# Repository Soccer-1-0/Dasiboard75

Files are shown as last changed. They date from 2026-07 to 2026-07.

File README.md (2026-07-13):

# Dasiboard75

This is my attempt at creating a keyboard with 84 keys, with backlights, a rotary encoder, a slide potentiometer, a OLED screen, and a power switch, using just the 19 usable pins of a XIAO NRF52840 Plus. I named it dasiboard75 because I liked the unique way to spell it and it just sounds like a cool keyboard.
Render

## CAD
Cadding everything together was the best part, since I could easily see the results fast and I didn't have to worry about any problems later in firmware. The keys will also be colored, since there is a keyset that I sourced that provides variations of light green keys, I just didn't want to add color to every individual key. I also made custom knobs for both the slide potentiometer and the rotary encoder! Dasiy flower for the encoder! Also, since I couldn't fit the file size in github for the assembly, view and download the complete assembly here: https://a360.co/4feVppu

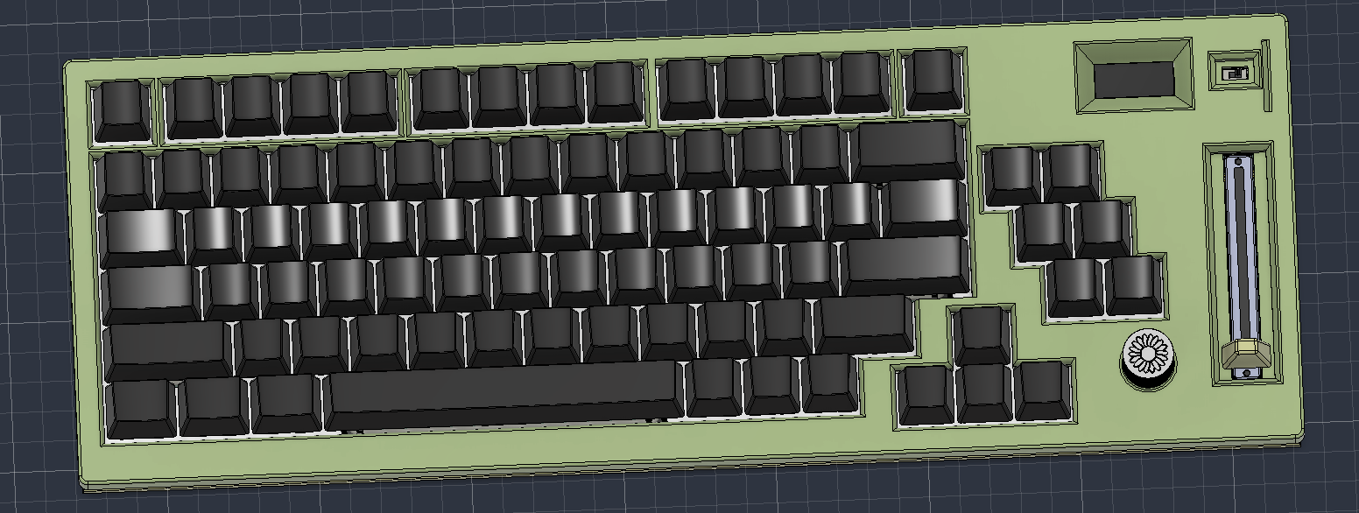
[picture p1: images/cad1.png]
cad1

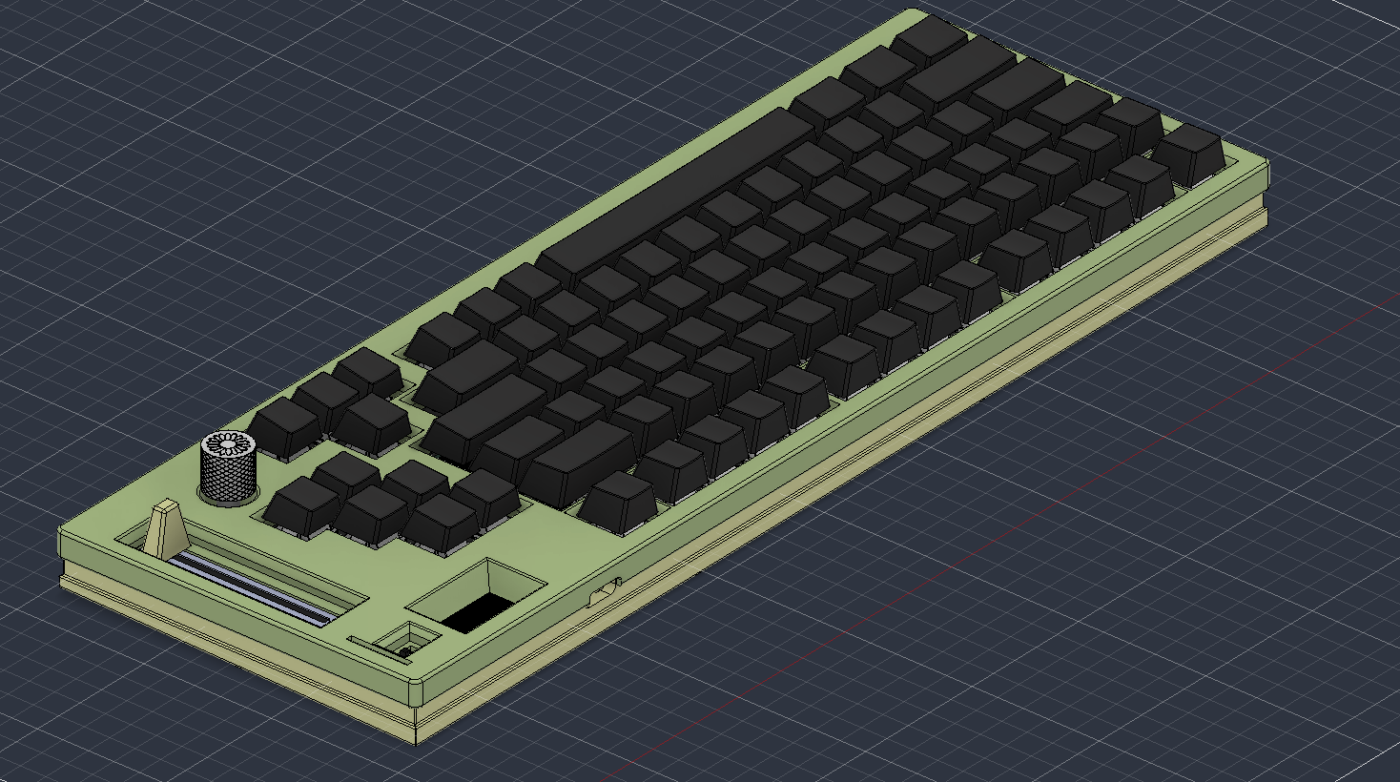
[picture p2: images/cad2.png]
cad2


## Schematic
My schematics are so cooked that I need three images for this. The leds took so much space, but it only takes on gpio pin. I used the japanese duplex matrix, which is why there are two keys for each column in the schematic drawing for the switiches. The duplex matrix works with scanning with the different directions of diodes to be able to double the amount of keys on a keyboard, which is the main reason I was able to make a full keyboard with less pins.
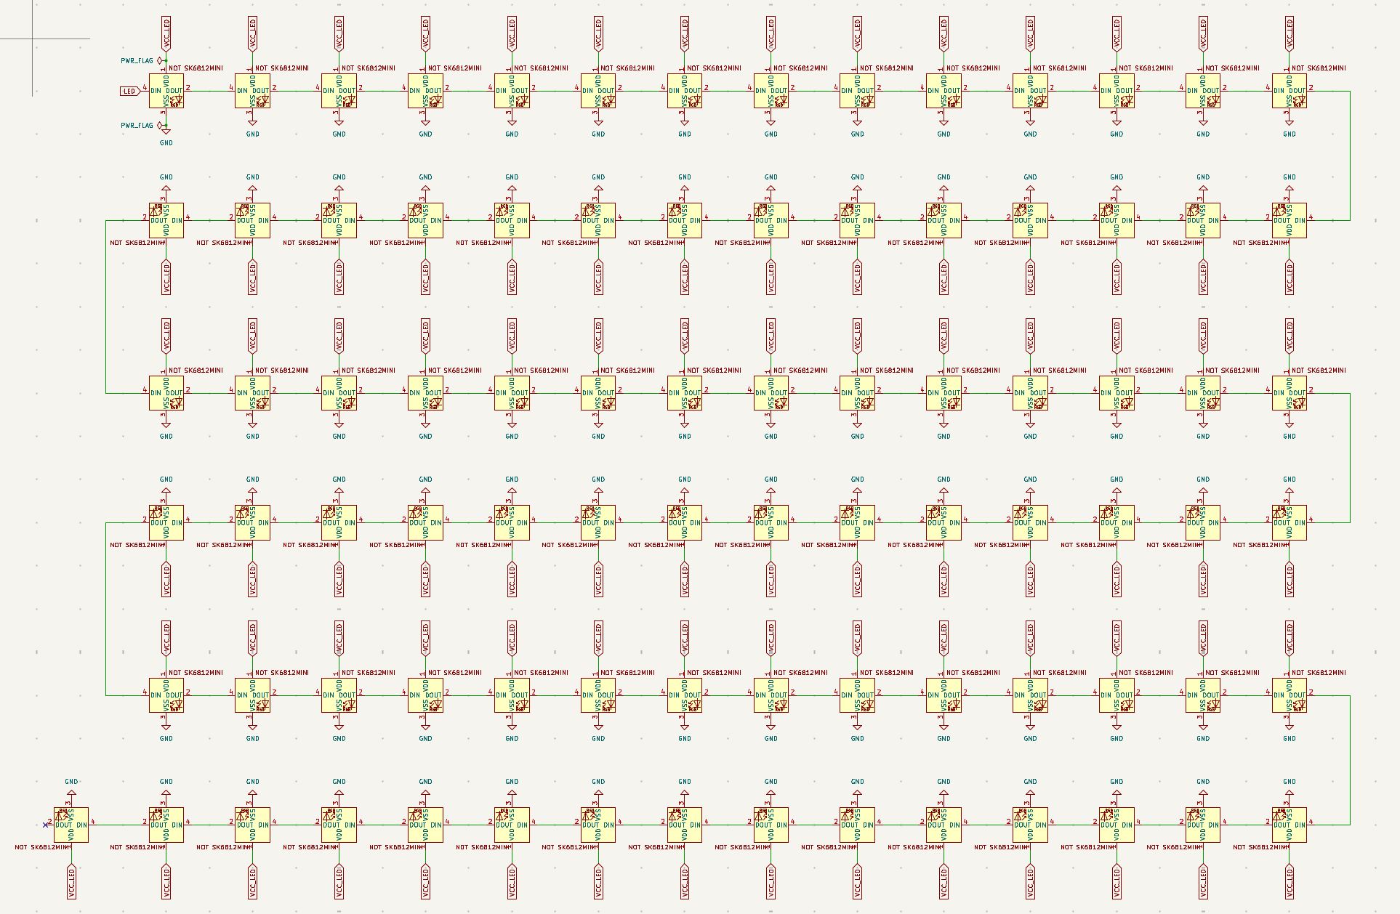
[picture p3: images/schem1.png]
schem1

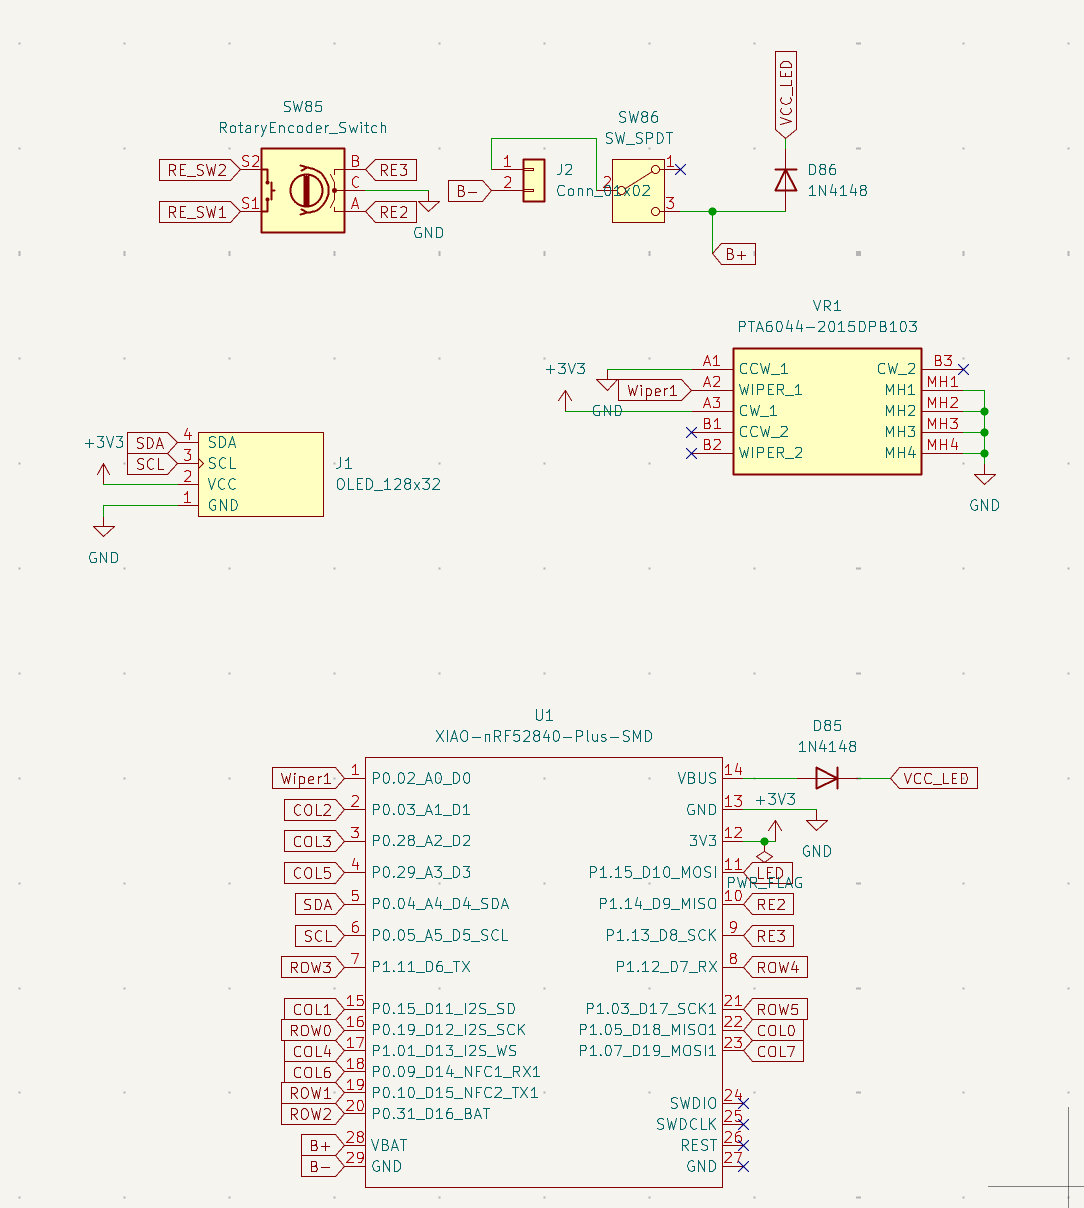
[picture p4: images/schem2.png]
schem2

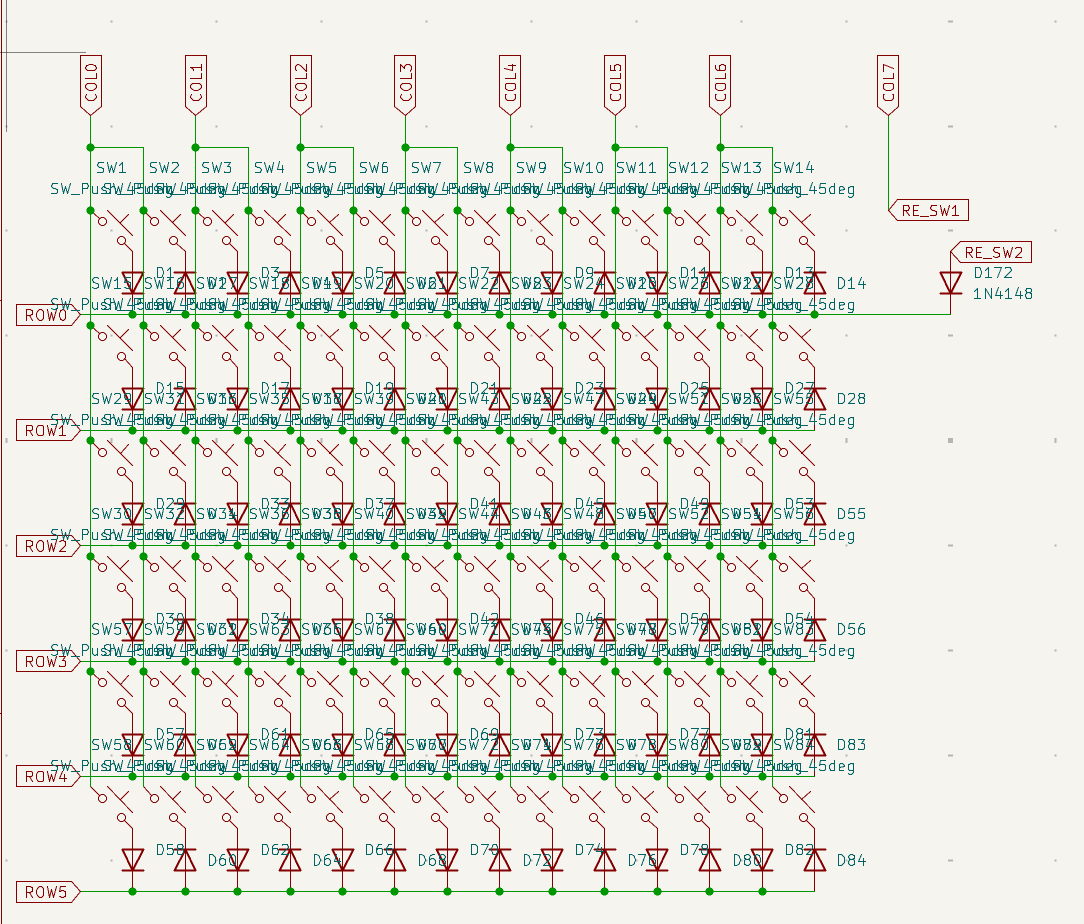
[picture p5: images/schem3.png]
schem3


## PCB
The routing of this took so long, since I used a 7x7(2) matrix for it, I had to move all the switiches to make sure they all connected the same way. The routing of the leds were even worse.
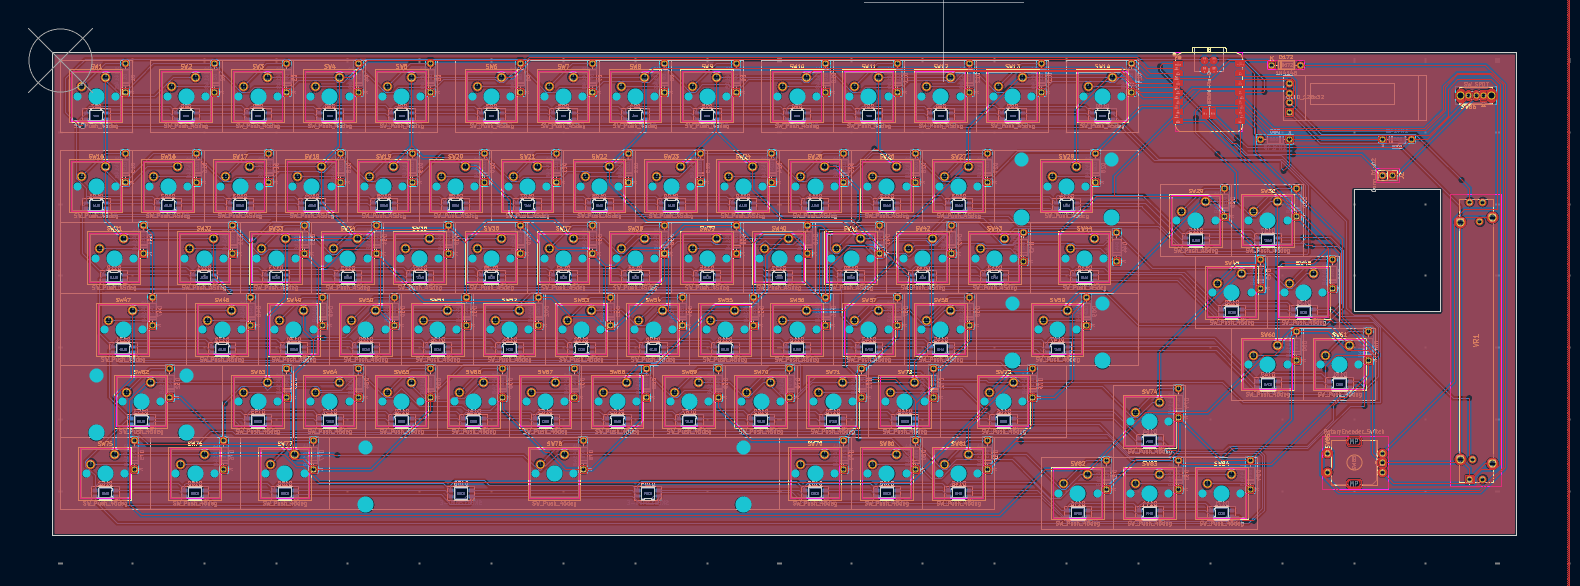
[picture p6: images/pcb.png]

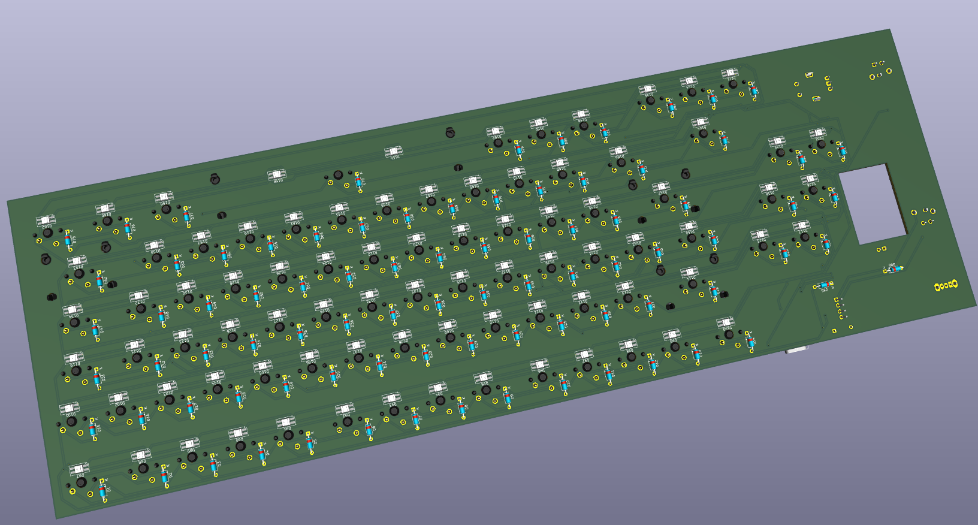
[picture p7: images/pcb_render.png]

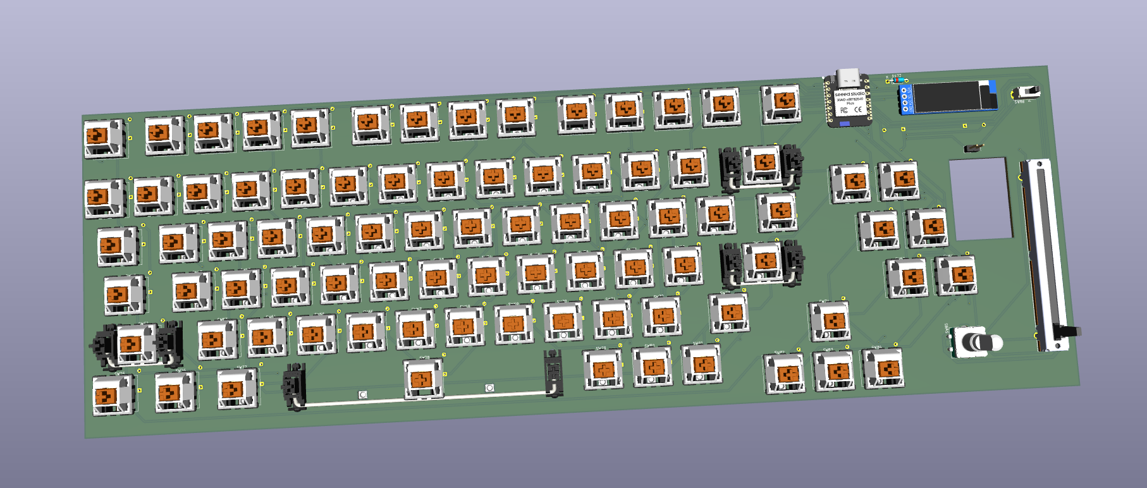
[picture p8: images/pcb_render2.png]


## Firmware
Still in progress, am trying to find a way for it to work with ZMK firmware, since some of my features are not supported with ZMK, but I really want to use the energy saving ways of bluetooth of ZMK. UPDATE: firmware: https://github.com/Soccer-1-0/zmk-config

## Casing
The casing took a very annoying long time. The plate itself took a long time since I used a keyboard layout generator, but then moved the keys during the routing process for a smaller pcb. I also had to add a bunch of holes for heat inserts, and screws, and the heads of the screws since I used a bottom mount for my keyboard (search it up, its a keyboard type of conencting between the plates and casing). But overall, I like how the casing ended up, I kinda wanted to add another part of casing to protect the keys and knobs, but we'll see if I actuall add it later.
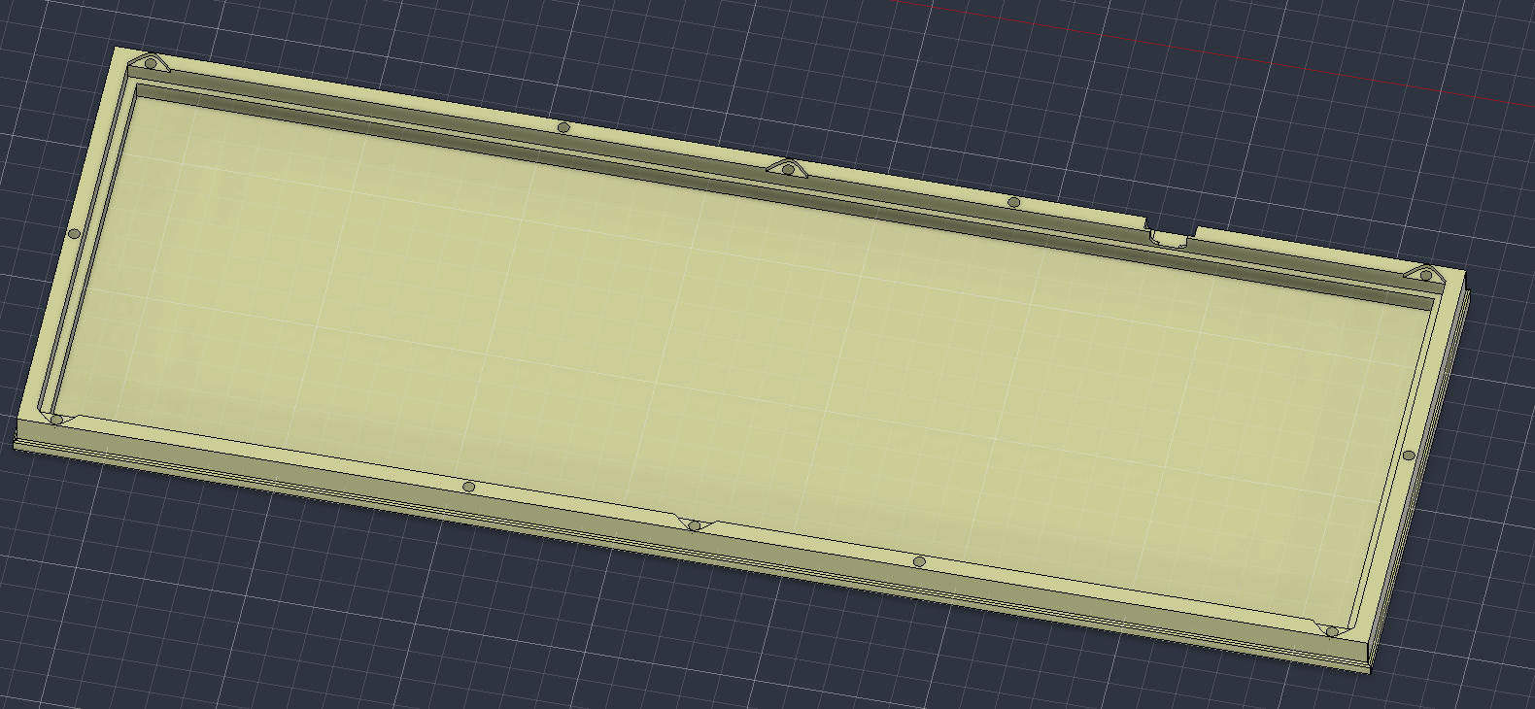
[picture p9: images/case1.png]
case1

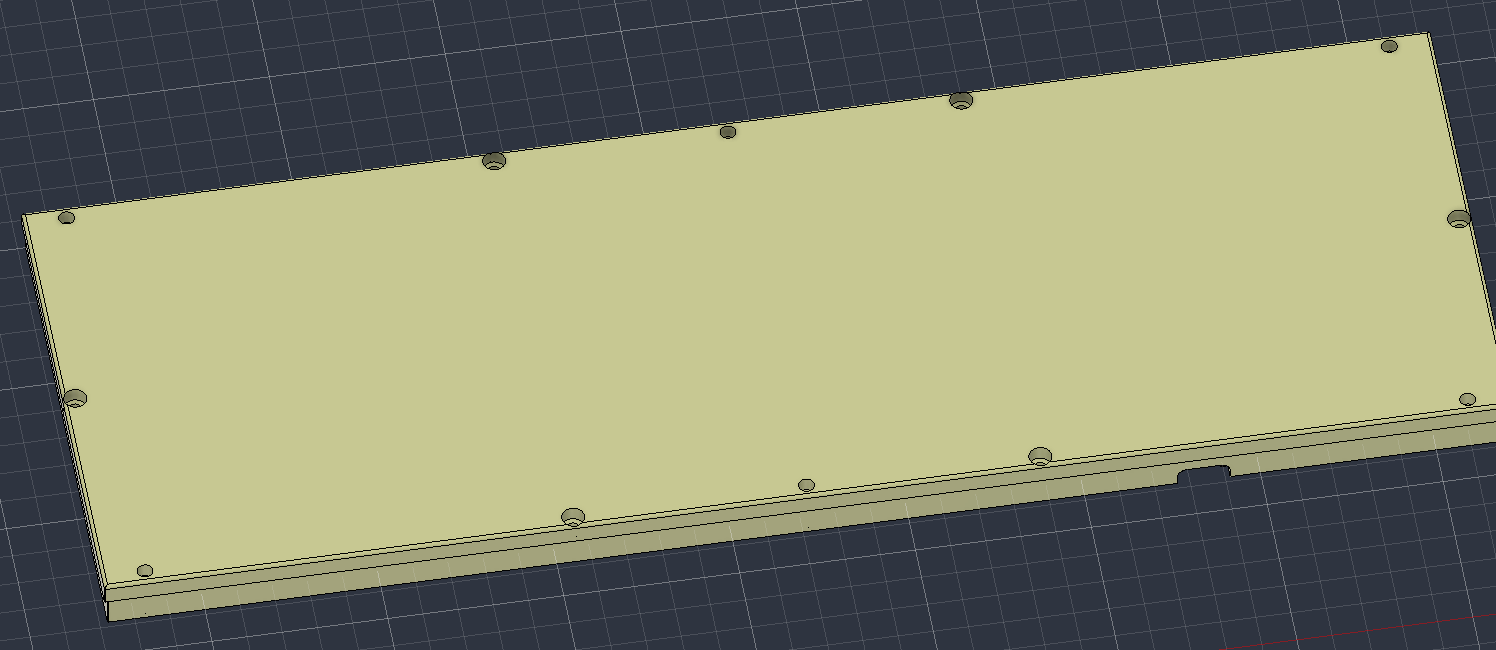
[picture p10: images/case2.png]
case2

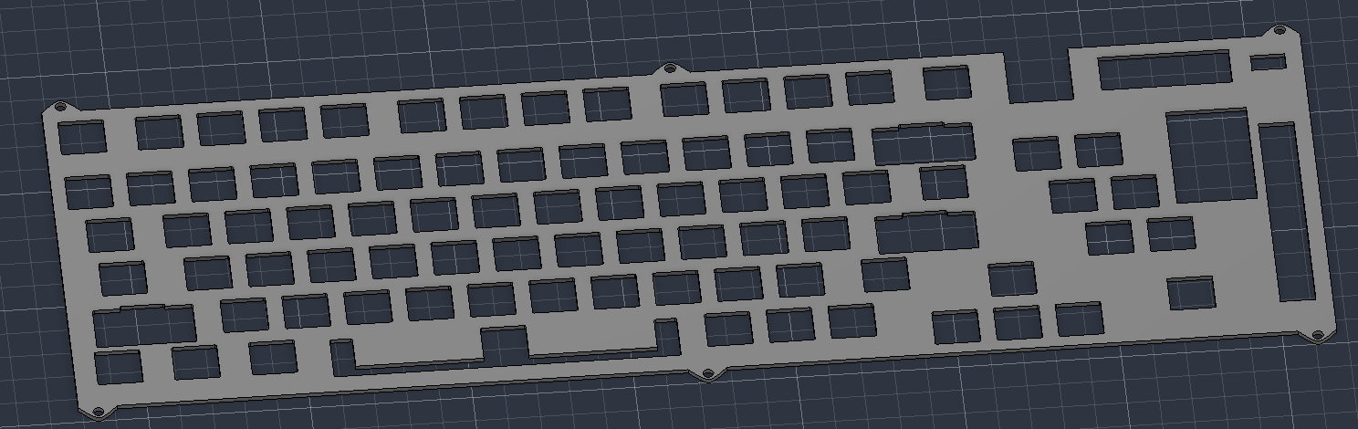
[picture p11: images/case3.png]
case3

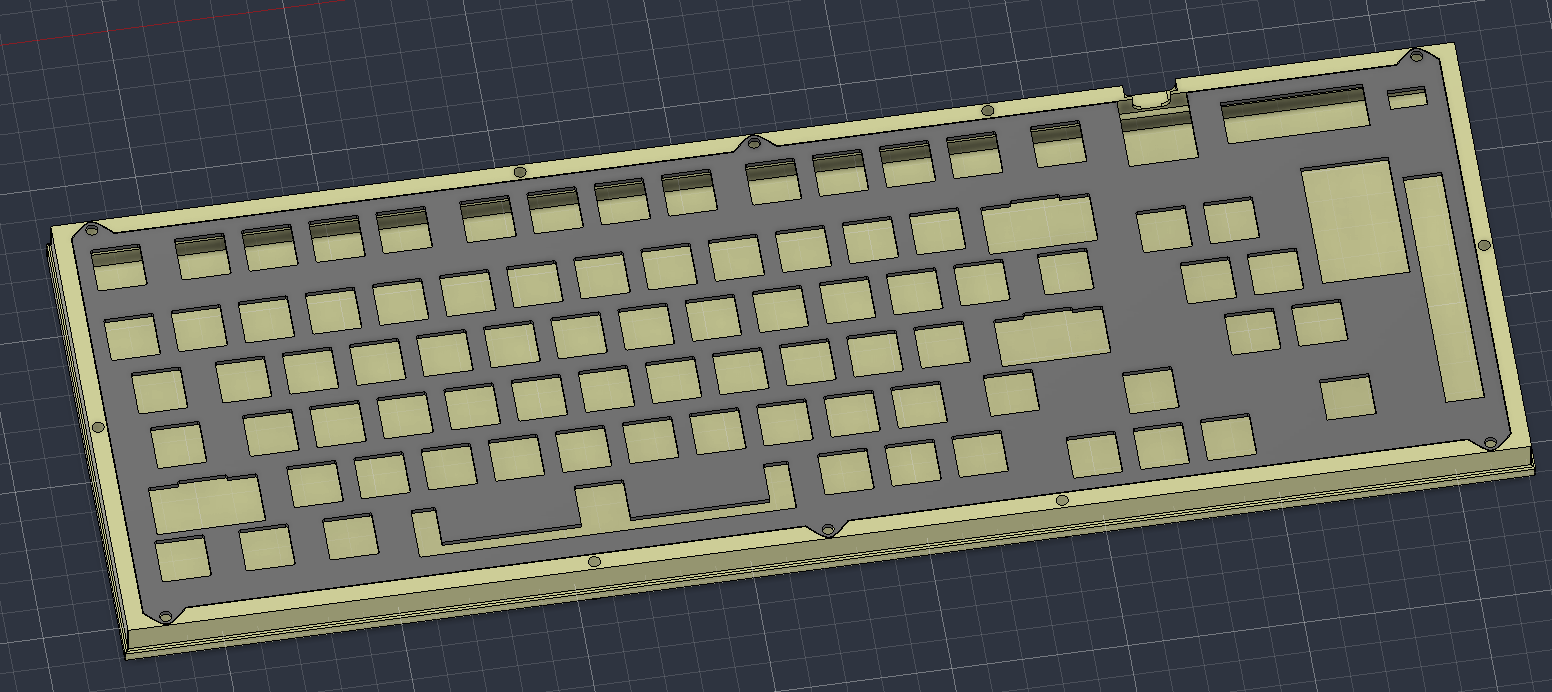
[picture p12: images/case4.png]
case4

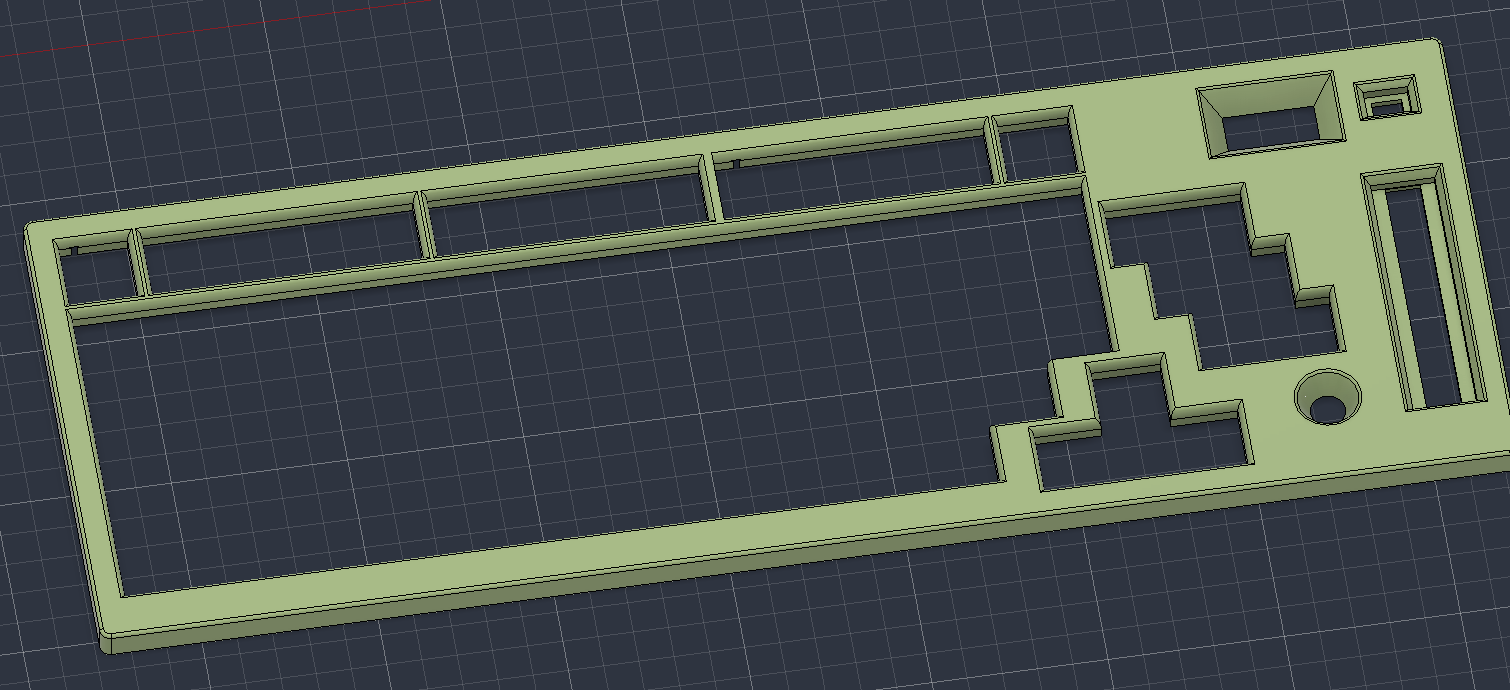
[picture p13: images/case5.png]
case5

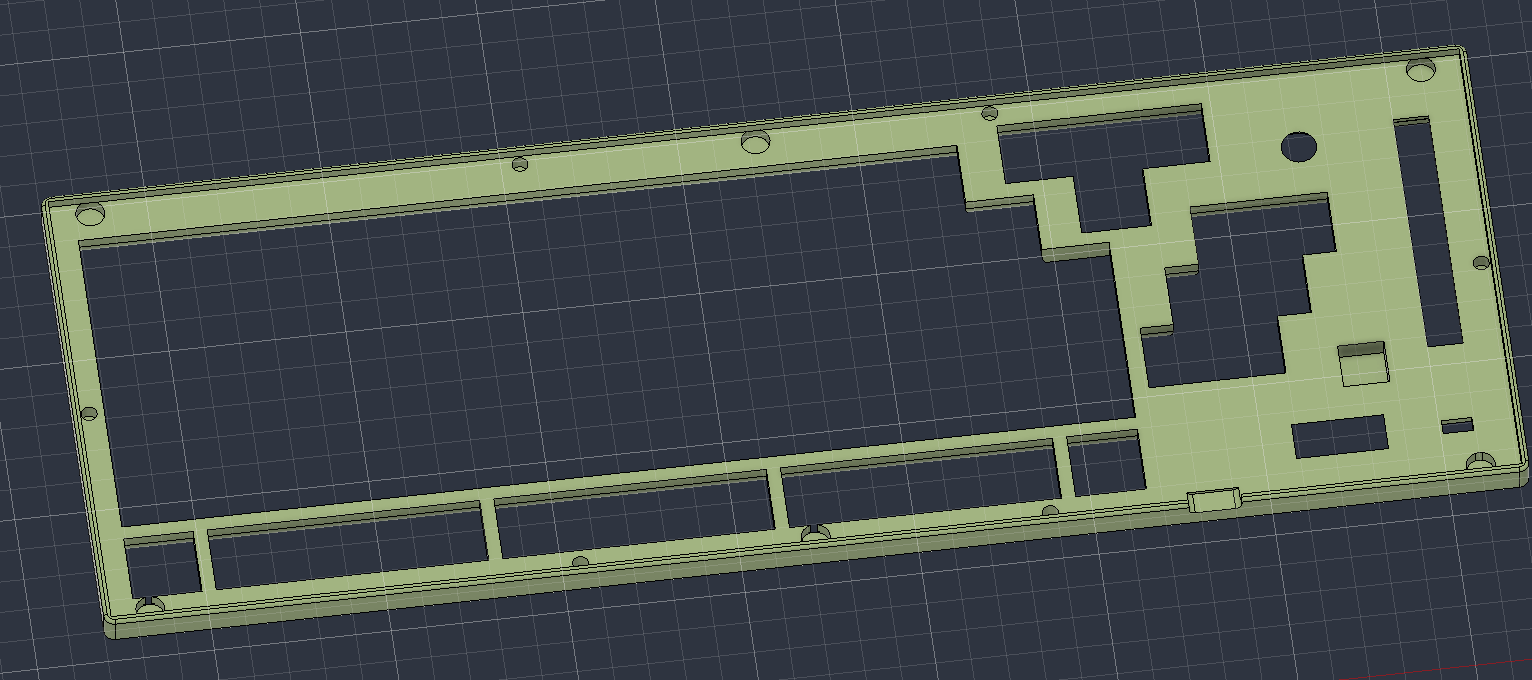
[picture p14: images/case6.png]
case6

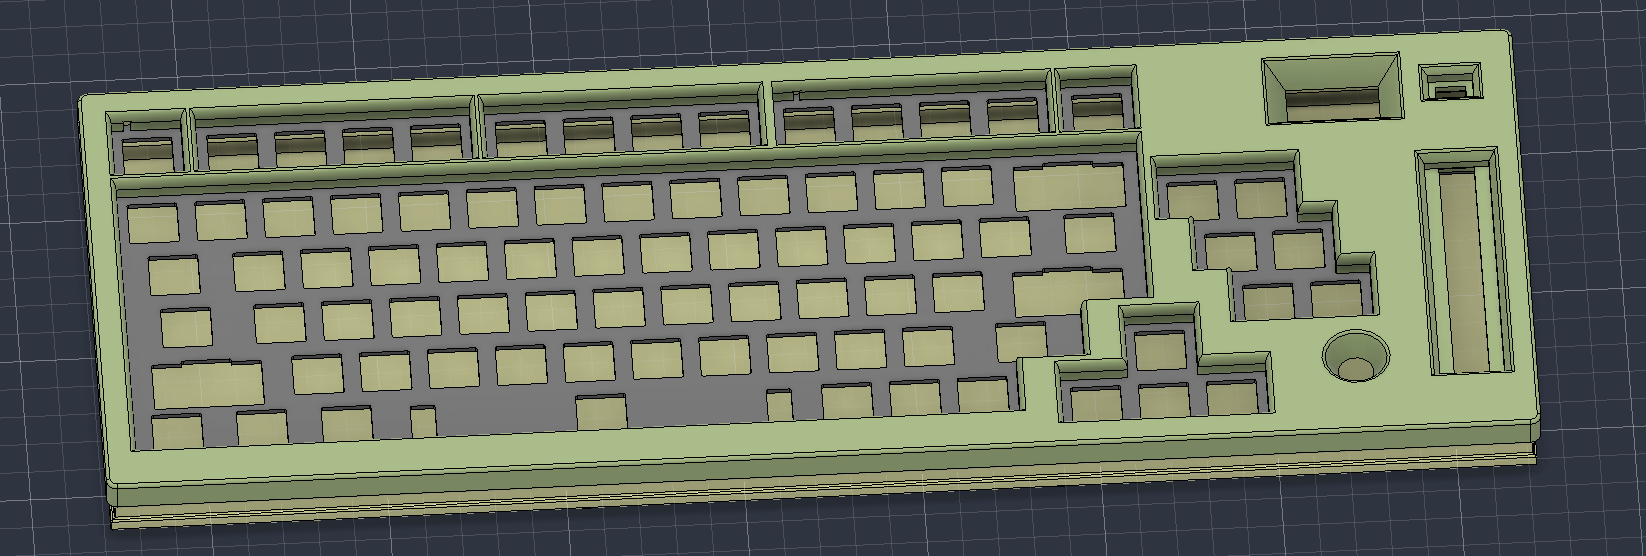
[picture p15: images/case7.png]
case7


## BOM
- PCB
- Casing
- Keycaps
- 1N4148 Diodes
- 0.91 OLED Display
- 6.0U and 2.0 stabilizers
- Key Switches
- Rotary Encoder
- Slide Potentiometer
- Xiao NRF52840
- SK6812 Mini E LEDs
- SPDT Switch
- Rotary and Slider Knobs
- Litho Battery
- M3x18 Screws
View more indepth in the BOM file

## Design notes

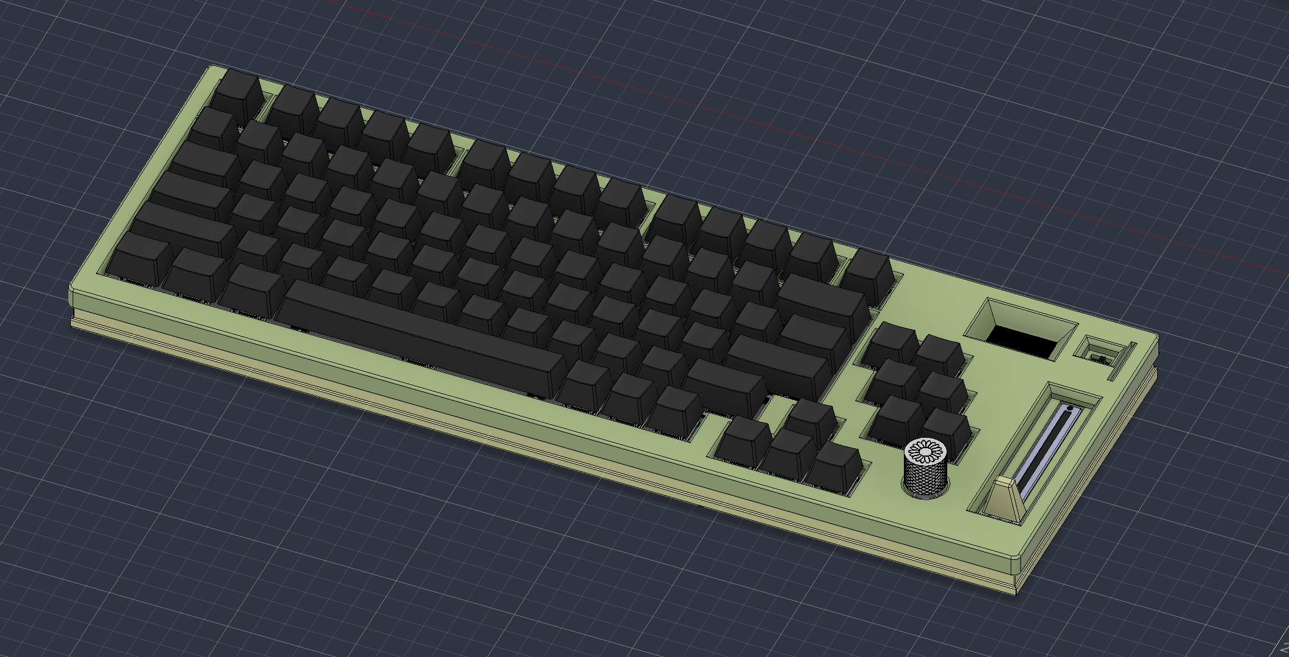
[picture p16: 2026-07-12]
images/Render.png

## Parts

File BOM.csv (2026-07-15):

Part | Quantity | Purpose | Shown Price | Link
PCB | 1 | Main body for components and wiring |  | JLCPCB
Casing | 1 | Holds the pcba and other parts |  | 3d printed (Printing Legion I think)
Keycaps | 84 | For the keyswitches, and found a good set | $18.01 | https://www.aliexpress.us/item/3256807174517233.html?mp=1&_randl_shipto=US
1N4148 Diodes | 86 | For the keyswitches to be able to work | $2.51 | aliexpress.us/item/3256811580628264.html?spm=a2g0o.detail.0.0.1678d7Qxd7QxvC&mp=1&pdp_npi=6%40dis%21USD%21USD%202.63%21USD%202.51%21%21USD%202.51%21%21%21%402103138417839779934458576e1043%2112000056498191665%21ct%21US%217763341167%21%211%210%21&gatewayAdapt=glo2usa&_randl_shipto=US
0.91 OLED Display | 1 | The display, for battery power and others | $2.48 | aliexpress.us/item/3256809902820804.html?spm=a2g0o.detail.0.0.28ebT1mST1mSgm&mp=1&pdp_npi=6%40dis%21USD%21USD%204.96%21USD%202.48%21%21USD%202.48%21%21%21%402103138417839779125795057e1043%2112000051099314066%21ct%21US%217763341167%21%211%210%21&gatewayAdapt=glo2usa&_randl_shipto=US
6.0U and 2.0 stabilizers | 1 | To stabilize the bigger keys | $5.78 | https://www.aliexpress.us/item/3256807050530252.html?curPageLogUid=pjmGXizb0fzy
Key Switches | 84 | For input so the keys actually work | $8.83 | https://www.aliexpress.us/item/3256804099108371.html?curPageLogUid=7E7eGrCkenkF
Rotary Encoder | 1 | The rotary knob for twist, turns, and push and pulls | $1.99 | https://www.aliexpress.us/item/3256805796819763.html?mp=1
Slide Potentiometer | 1 | The part for the sliding knob, for audio or brightness. | $2.78 | https://www.mouser.com/en/ProductDetail/Bourns/PTA6044-2015DPB103?qs=QARuOjD9jaFuTF8TgGb%252B8w%3D%3D
Xiao NRF52840 Plus | 1 | The microcontroller for everything | $10.40 | https://www.seeedstudio.com/Seeed-Studio-XIAO-nRF52840-Plus-p-6359.html
SK6812 Mini E LEDs | 84 | For backlighting behind every key | $3.64 | https://www.aliexpress.us/item/3256807677321116.html?mp=1
SPDT Switch | 1 | The on and off switch for the keyboard | $0.94 | https://www.aliexpress.us/item/3256806935214912.html?mp=1
Rotary and Slider Knobs | 1 | To have a smoother twist and pulls |  | 3d printed (Printing Legion I think)
Litho Battery | 1 | Battery for the bluetooth keyboard | $8.72 | aliexpress.us/item/3256806397828855.html?spm=a2g0o.detail.0.0.70d5xdl5xdl5jD&mp=1&pdp_npi=6%40dis%21USD%21USD%208.46%21USD%205.16%21%21USD%205.16%21%21%21%402103138417839775579492725e1043%2112000037729349745%21ct%21US%217763341167%21%211%210%21&pdp_ext_f=%7B"cart2PdpParams"%3A%7B"pdpBusinessMode"%3A"retail"%7D%7D&gatewayAdapt=glo2usa&_randl_shipto=US
M3x20 Screws | 1 | Holds and keeps the casing together | $6.89 | aliexpress.us/item/3256801577740069.html?spm=a2g0o.cart.0.0.65ad38daEhH0D6&mp=1&pdp_npi=6%40dis%21USD%21USD%207.33%21USD%206.89%21%21USD%206.89%21%21%21%402101c4ea17840741258056476e0ee8%2112000017472790054%21ct%21US%217763341167%21%211%210%21&gatewayAdapt=glo2usa&_randl_shipto=US
M3x22 Screws | 1 | Holds and keeps the casing together | $3.68 | https://www.aliexpress.us/item/3256808936789372.html?mp=1
Total Prices (Plus Shipping)
JLCPCB | $42.16
Aliexpress | $85.78
SeeedStudio | $17.81
Mouser | $12.74
Total | $160

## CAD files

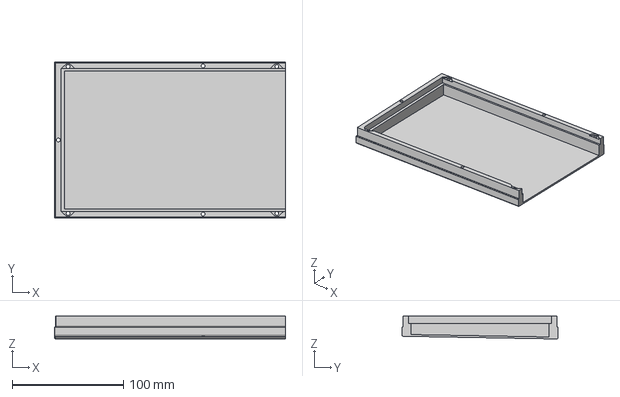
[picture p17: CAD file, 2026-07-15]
Production/3D/Bottom Casing Left.step
208.0 x 140.4 x 20.7 mm

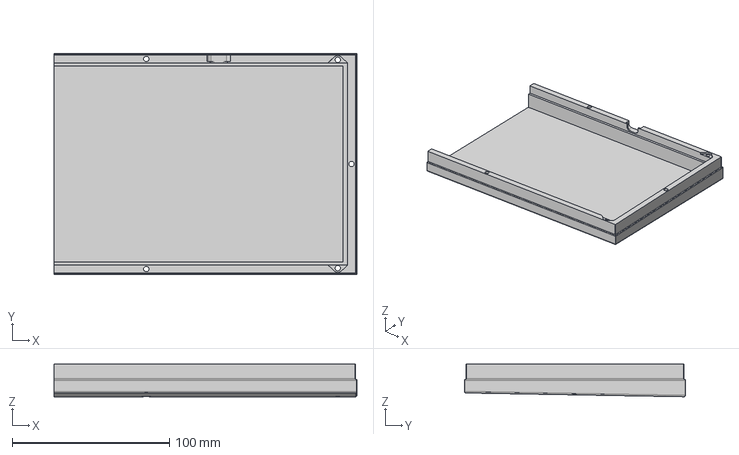
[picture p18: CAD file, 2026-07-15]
Production/3D/Bottom Casing Right.step
192.4 x 140.4 x 20.7 mm

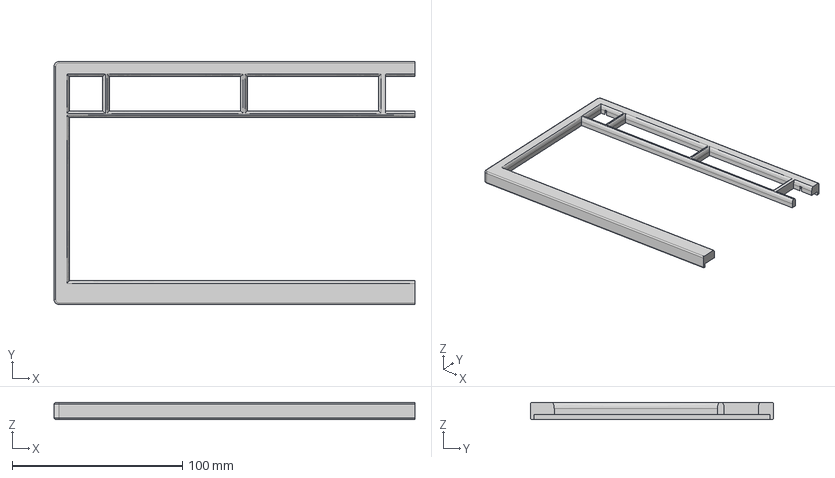
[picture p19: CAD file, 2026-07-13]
Production/3D/Top Case Left.step
212.0 x 142.8 x 10.0 mm

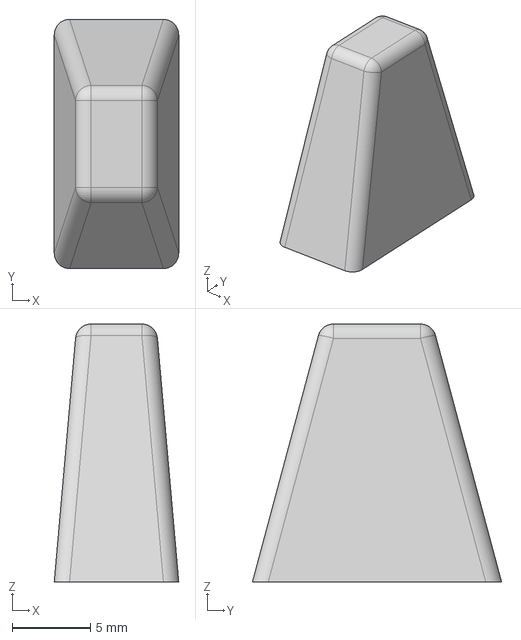
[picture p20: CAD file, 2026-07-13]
Production/3D/SlideKnob.step
7.96 x 15.9 x 16.5 mm

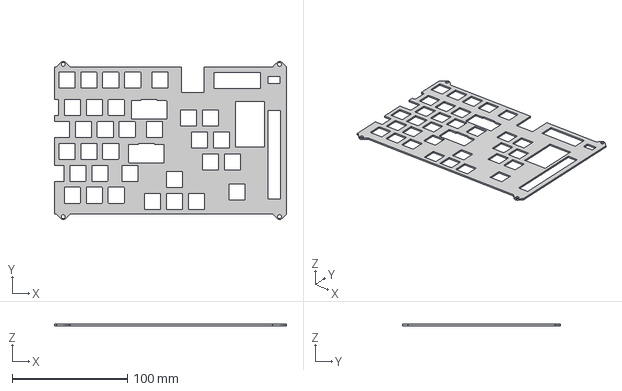
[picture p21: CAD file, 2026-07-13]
Production/3D/Plate Right Half.step
201.6 x 137.5 x 1.50 mm

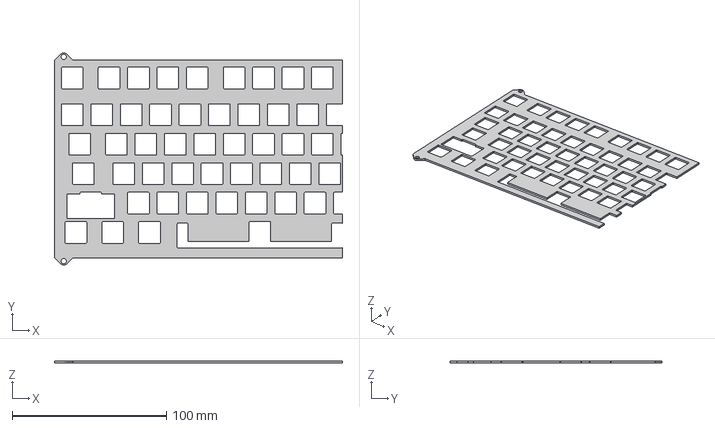
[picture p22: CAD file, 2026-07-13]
Production/3D/Plate Left half.step
186.4 x 137.5 x 1.50 mm

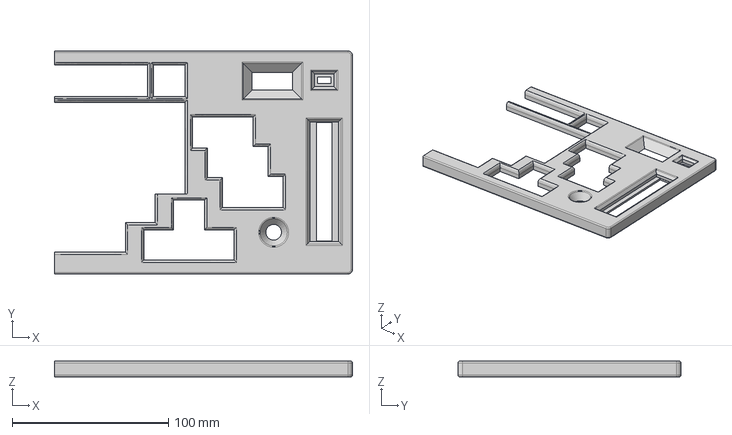
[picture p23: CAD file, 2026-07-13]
Production/3D/Top Case Right.step
190.8 x 142.8 x 10.0 mm

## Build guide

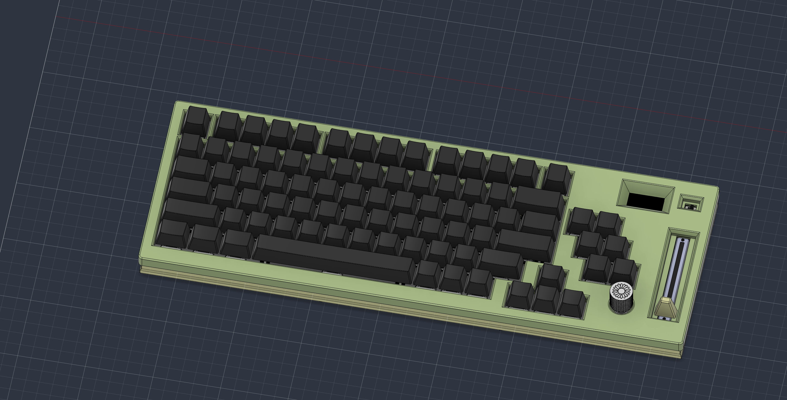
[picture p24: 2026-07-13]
CAD/assemble area.png

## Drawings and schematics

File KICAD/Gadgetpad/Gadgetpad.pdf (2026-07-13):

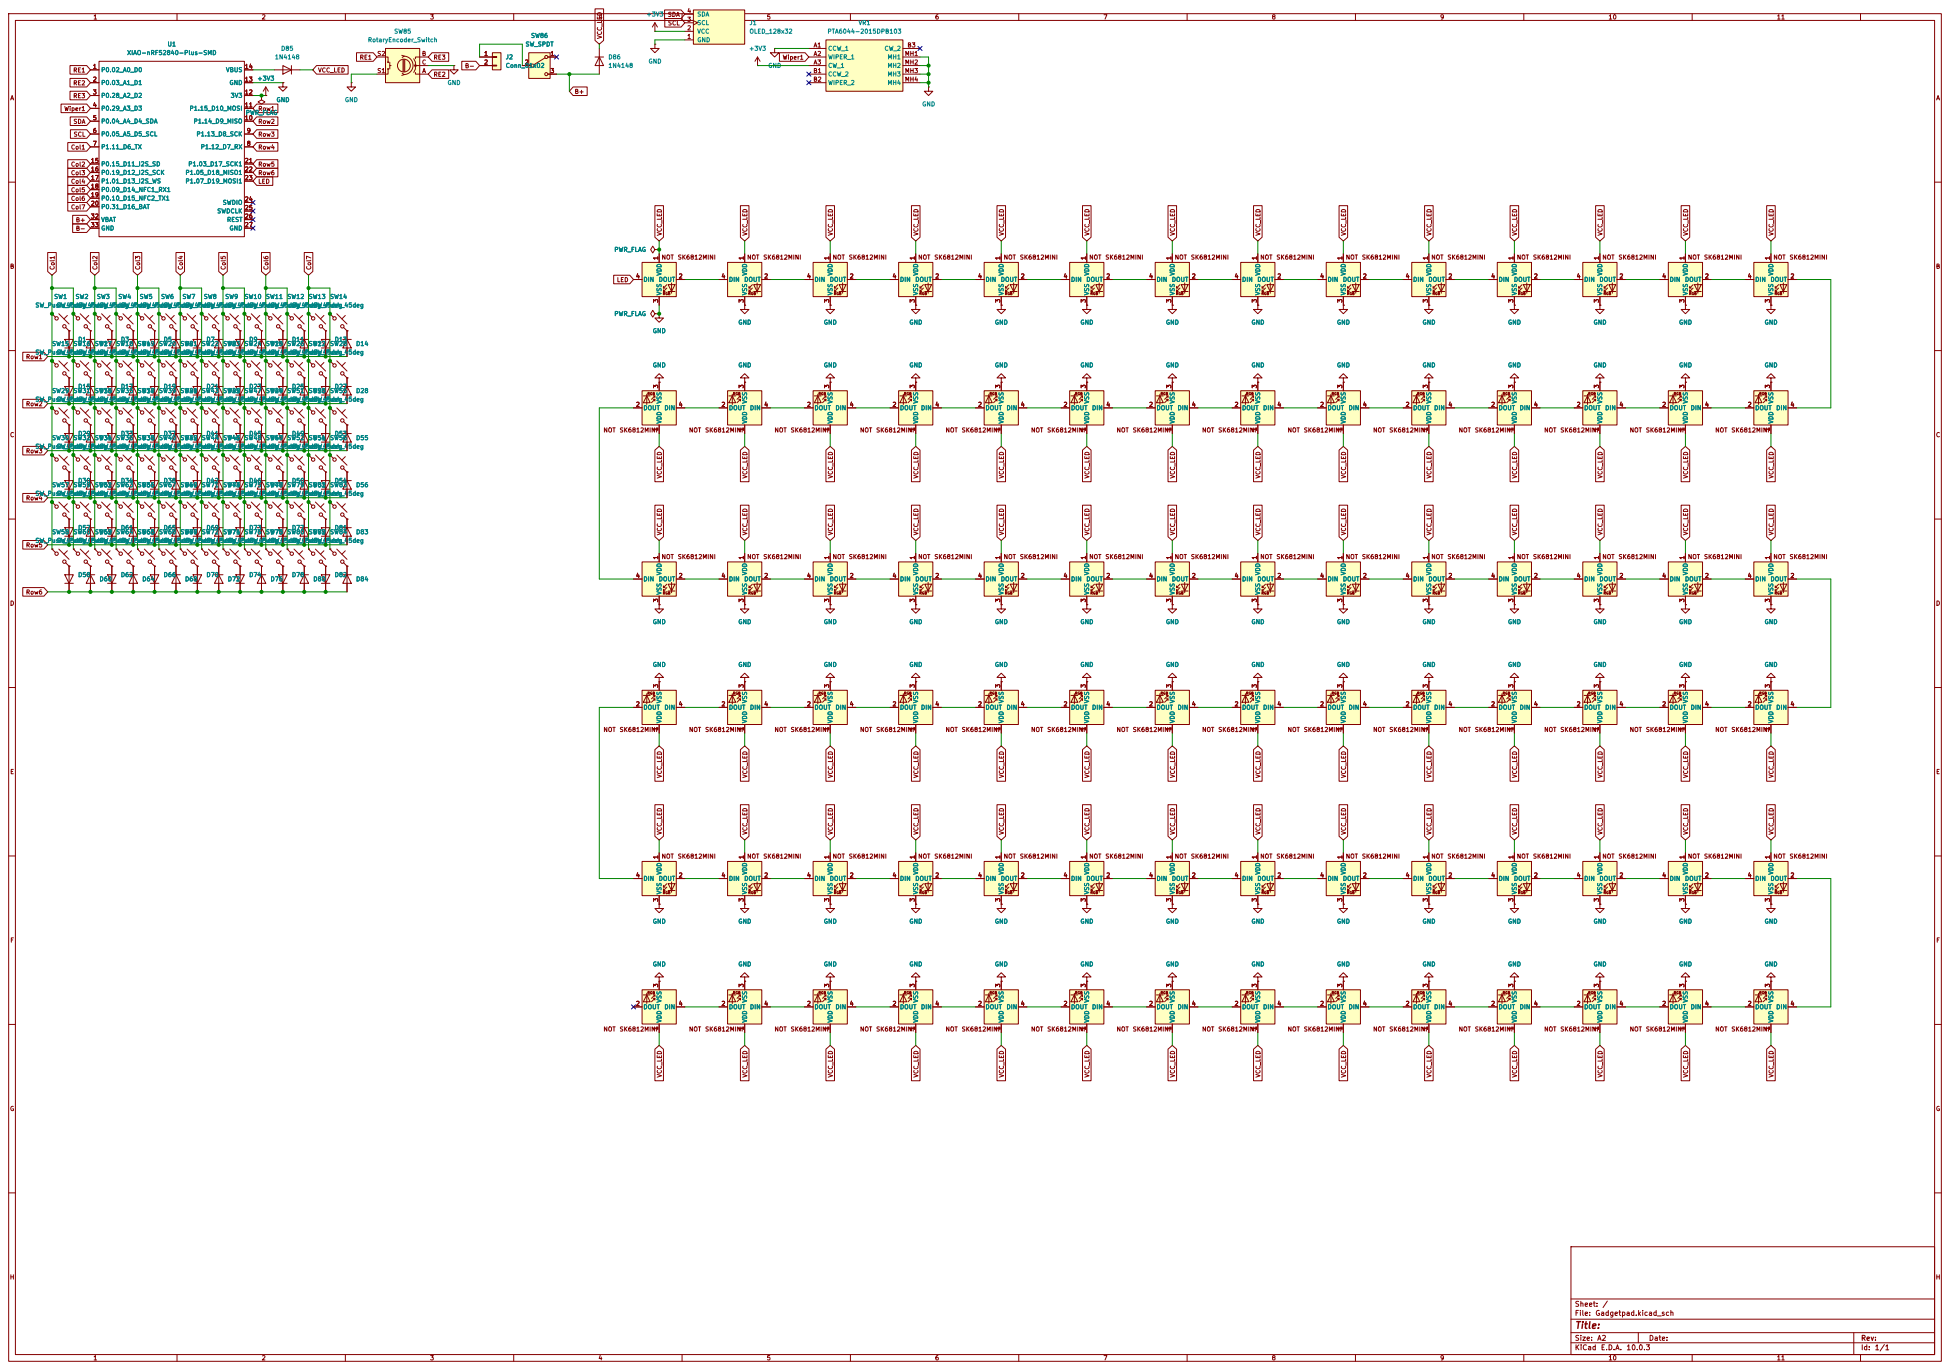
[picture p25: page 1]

3 DIN 4 GND GND GNDVDD

Size: A2 | Rev:
KiCad E.D.A. 10.0.3 | Id: 1/1
